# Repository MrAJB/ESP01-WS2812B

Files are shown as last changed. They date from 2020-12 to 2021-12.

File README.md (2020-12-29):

## Introduction
This repo documents the development of a small ESP-01 breakout board to support controlling two WS2812B LED strips and a Dallas DS18B20 temperature sensor. This allows for easy integration with HomeAssistant through ESPHome. 

Note that I'm just developing this stuff in my spare time and I'm far from an expert. Development may be slow and I cannot make any promises on the quality of this board. However, feel free to look around, maybe there's something useful for you in there!

## Hardware Overview
A schematic overview of the breakout board can be found [here](Hardware/esp01-ws2812b-breakout.pdf). As an be seen, this simple board allows to fit an ESP-01. Furthermore, it contains two level-shifters to control 5V data lines. The board is prepared to mount a DS18B20 temperature sensor, if desired. Lastly, a header to interface with the GPIO0 pin can be added, to further expand this board.

The layout and routing of V1 are finished:
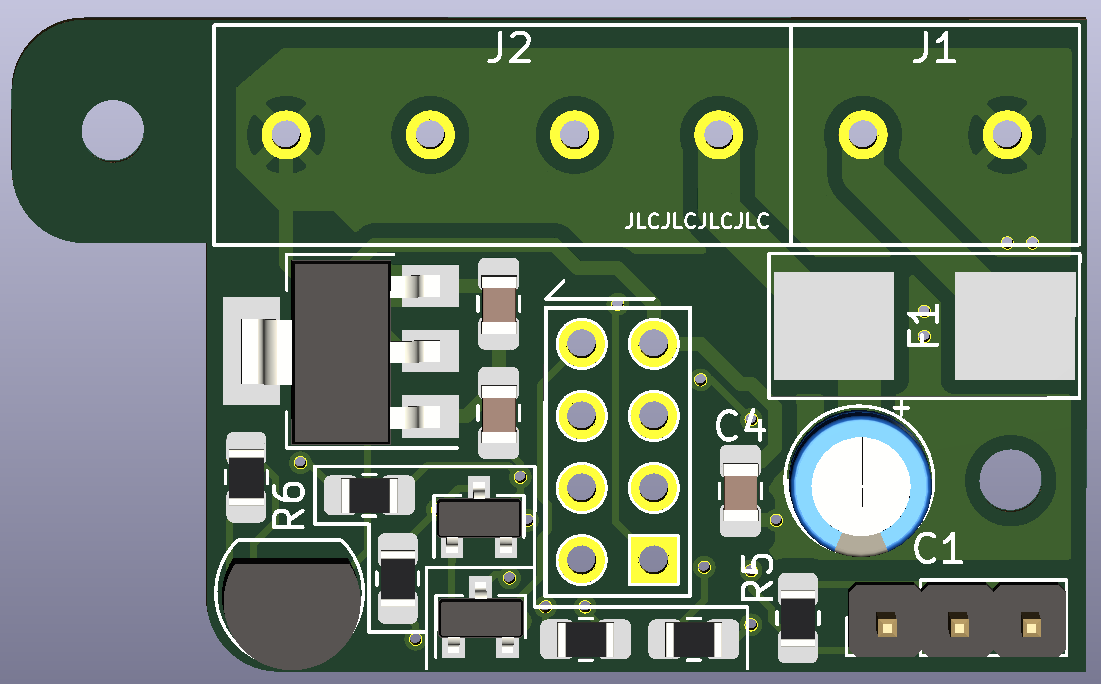
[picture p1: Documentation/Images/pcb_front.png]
pcb_front

(Note: the cutout in the lower left section aims to provide clearance for the WiFi antenna to improve the ESP's WiFi range.)

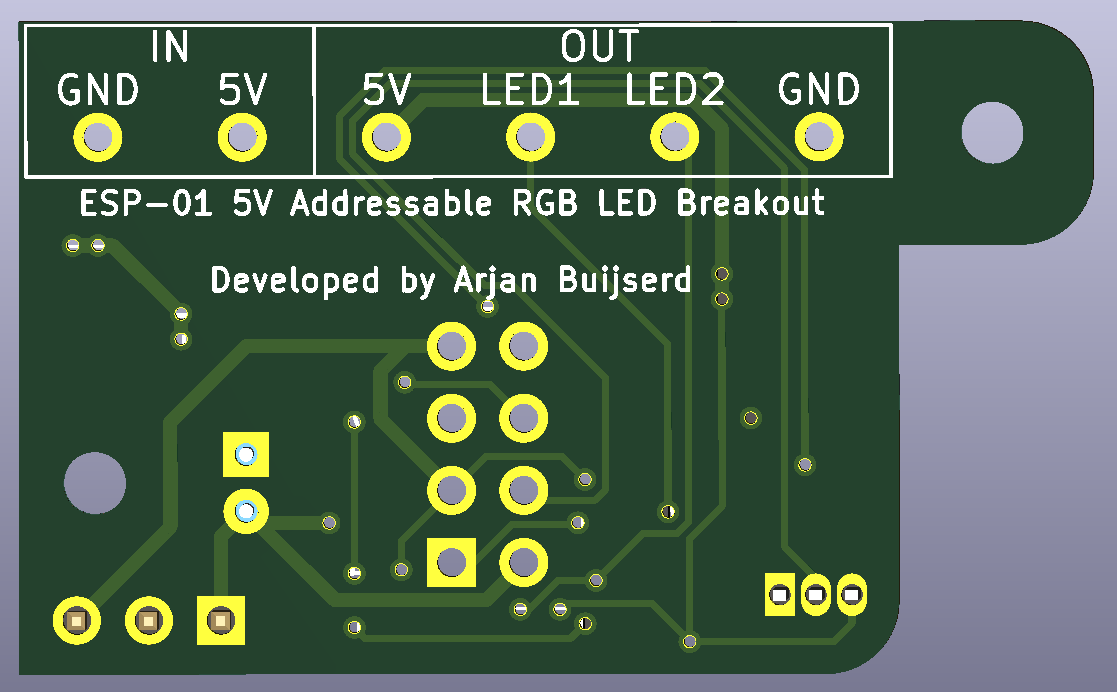
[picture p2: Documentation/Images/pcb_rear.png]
pcb_rear


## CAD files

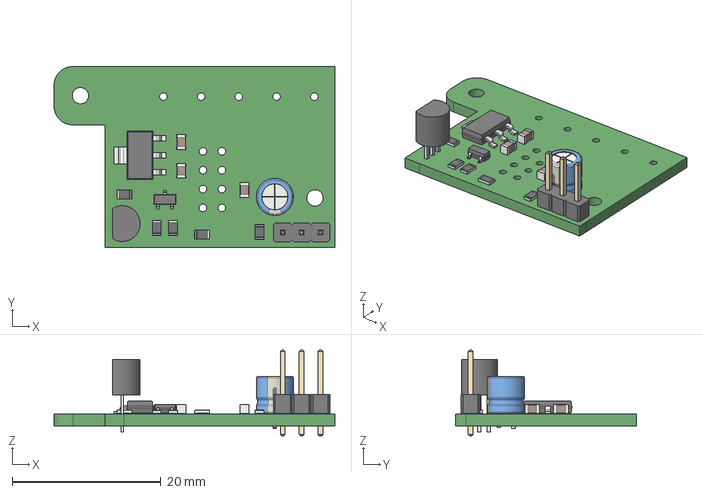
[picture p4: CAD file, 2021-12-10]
Hardware_Housing/esp01-ws2812b-breakout.step
37.8 x 24.4 x 11.5 mm

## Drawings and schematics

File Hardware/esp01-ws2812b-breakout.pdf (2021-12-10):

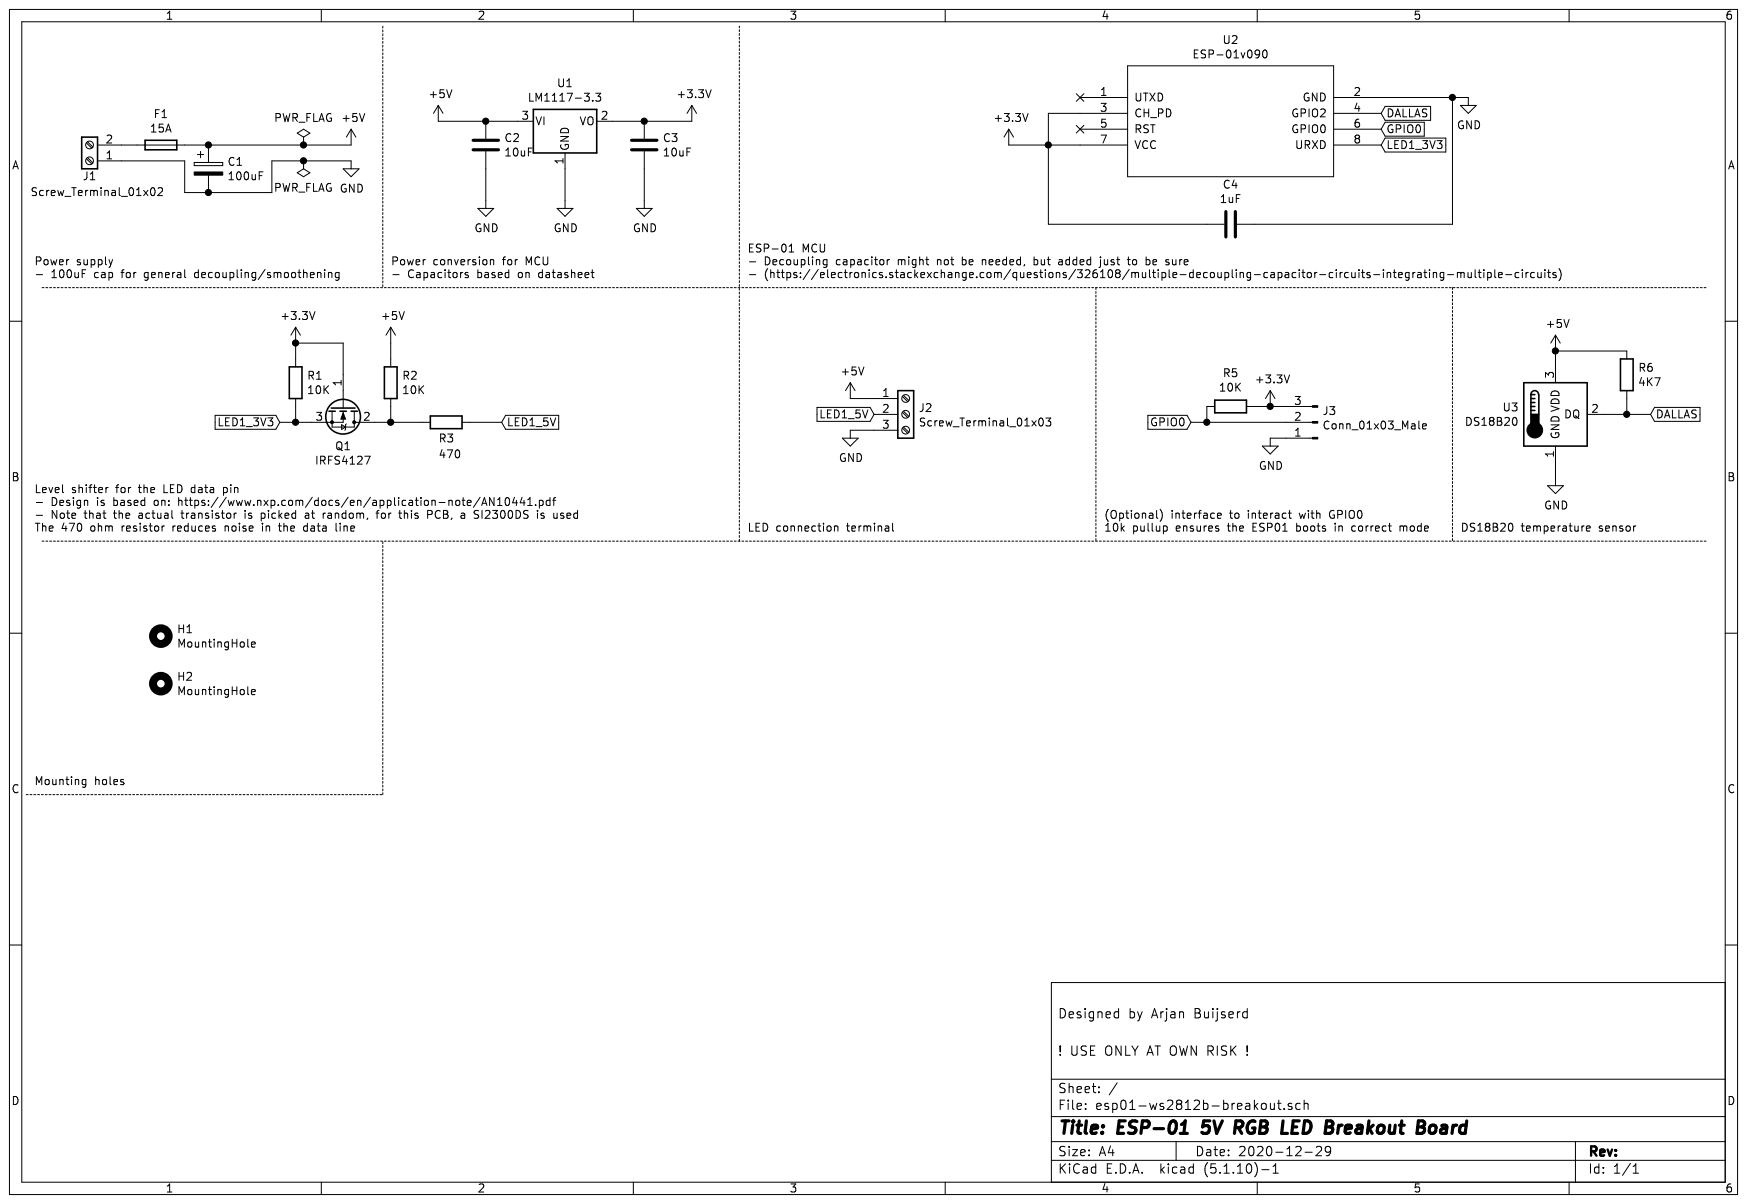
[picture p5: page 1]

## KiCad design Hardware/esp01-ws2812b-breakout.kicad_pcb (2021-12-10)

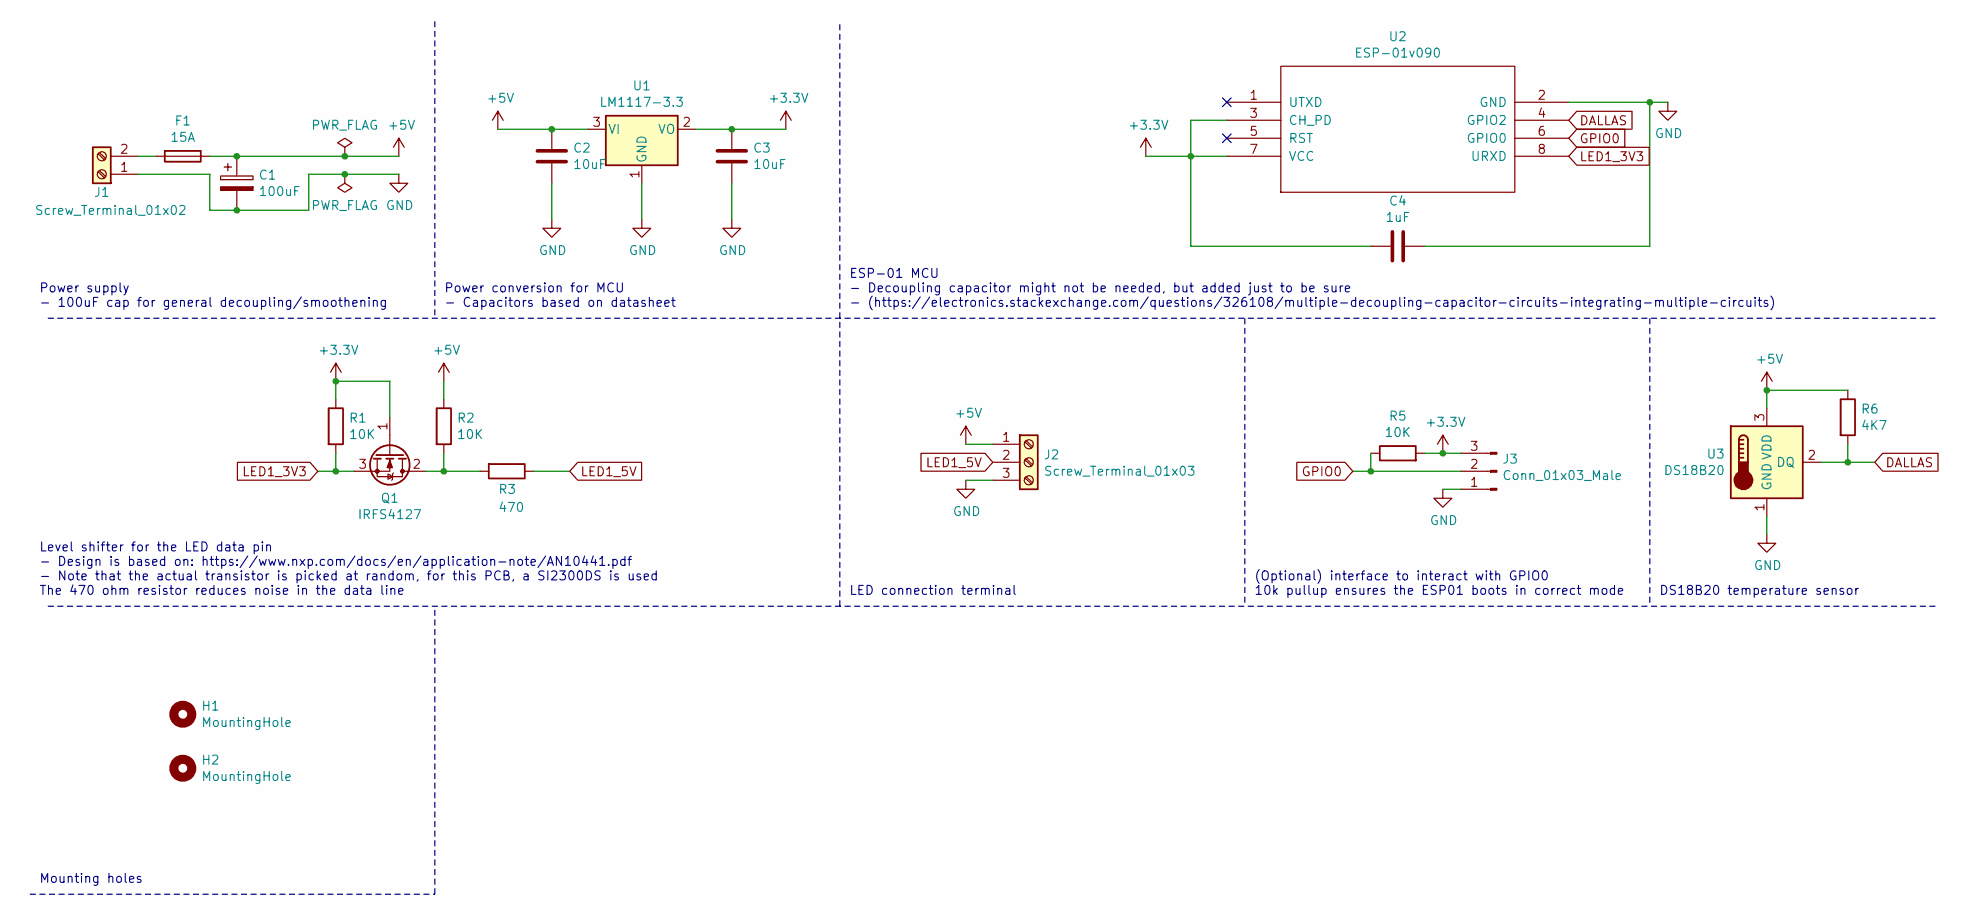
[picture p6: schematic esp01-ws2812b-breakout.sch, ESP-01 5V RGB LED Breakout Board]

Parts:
C1: 100uF; CP_Radial_D5.0mm_P2.00mm
C2, C3: 10uF; C_0805_2012Metric_Pad1.18x1.45mm_HandSolder
C4: 1uF; C_0805_2012Metric_Pad1.18x1.45mm_HandSolder
F1: 15A; 1808_SMD_Fuse_Holder
H1, H2: MountingHole; MountingHole_2.2mm_M2
J1: Screw_Terminal_01x02; 0102-blue-terminal
J2: Screw_Terminal_01x03; 0103-blue-terminal
J3: Conn_01x03_Male; PinHeader_1x03_P2.54mm_Vertical
Q1: IRFS4127; SOT-23_DS-REVERSED
R1, R2, R5: 10K; R_0805_2012Metric_Pad1.20x1.40mm_HandSolder
R3: 470; R_0805_2012Metric_Pad1.20x1.40mm_HandSolder
R6: 4K7; R_0805_2012Metric_Pad1.20x1.40mm_HandSolder
U1: LM1117-3.3; SOT-223
U2: ESP-01v090; ESP-01
U3: DS18B20; TO-92_Inline

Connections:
+3V3: C3.1, C4.2, J3.3, Q1.1 (G), R1.1, R5.2, U1.2 (VO), U2.3 (CH_PD), U2.7 (VCC)
+5V: C1.1, C2.1, F1.1, J2.1, R2.1, R6.1, U1.3 (VI), U3.3 (VDD)
DALLAS: R6.2, U2.4 (GPIO2), U3.2 (DQ)
GND: C1.2, C2.2, C3.2, C4.1, J1.1, J2.3, J3.1, U1.1 (GND), U2.2 (GND), U3.1 (GND)
GPIO0: J3.2, R5.1, U2.6 (GPIO0)
LED1_3V3: Q1.3 (S), R1.2, U2.8 (URXD)
LED1_5V: J2.2, R3.1
unnamed: F1.2, J1.2
unnamed: Q1.2 (D), R2.2, R3.2

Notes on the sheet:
ESP-01 MCU - Decoupling capacitor might not be needed, but added just to be sure - (https://electronics.stackexchange.com/questions/326108/multiple-decoupling-capacitor-circuits-integrating-multiple-circuits)
Level shifter for the LED data pin - Design is based on: https://www.nxp.com/docs/en/application-note/AN10441.pdf - Note that the actual transistor is picked at random, for this PCB, a SI2300DS is used The 470 ohm resistor reduces noise in the data line
LED connection terminal
DS18B20 temperature sensor
Mounting holes
(Optional) interface to interact with GPIO0 10k pullup ensures the ESP01 boots in correct mode
Power conversion for MCU - Capacitors based on datasheet
Power supply - 100uF cap for general decoupling/smoothening

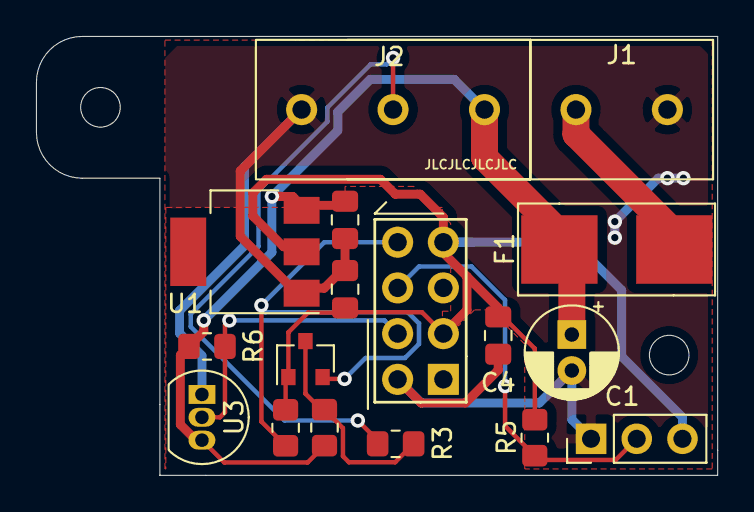
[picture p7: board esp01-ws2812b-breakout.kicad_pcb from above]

Board: 2 copper layers, 37.8 x 24.4 mm, 19 parts (0 on the bottom side), 9 nets.

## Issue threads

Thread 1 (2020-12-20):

WS2812B is 5V logic

MrAJB, 2020-12-20:
Create and test a simple logic level shifter to control the WS2812B with the ESP01:

https://hackaday.com/2016/12/05/taking-it-to-another-level-making-3-3v-and-5v-logic-communicate-with-level-shifters/

MrAJB, 2020-12-21:
Implemented logic level shifter and tested: LED is stable now.

Closed 2020-12-21.

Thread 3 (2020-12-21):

Supply voltage capacitor size TBD

MrAJB, 2020-12-21:
TODO:
- [x] Select the exact capacitor used
- [x] Assign the correct footprint
- [x] Update the PCB

MrAJB, 2020-12-21:
Done!

Closed 2020-12-21.

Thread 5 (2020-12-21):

Check C and R footprints

MrAJB, 2020-12-21:
Double check the footprints of all capacitors and resistors to make sure they match what parts I've actually ordered.

MrAJB, 2020-12-22:
Capacitors are 0603, resistors are 0805. Needs to be updated...

MrAJB, 2020-12-23:
Done, all is 0805 now.

Closed 2020-12-23.

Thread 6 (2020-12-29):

Check MOSFET's S-D orientation

MrAJB, 2020-12-29:
Double check if the source and drain of the MOSFET's are correctly placed on the PCB.

MrAJB, 2020-12-29:
Checked: they are correct.

Closed 2020-12-29.

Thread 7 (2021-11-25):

Check correct pin for LED

MrAJB, 2021-11-25:
It appeared that one pin was not suitable for driving the LED, as the ESP would not boot anymore. Check if the correct pin is now being used w.r.t. the pin in the test setup.

MrAJB, 2021-12-02:
It's the LED2 output terminal that works properly.

MrAJB, 2021-12-02:
Done!

Closed 2021-12-02.

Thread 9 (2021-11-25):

Terminal clashes with fuse holder

MrAJB, 2021-11-25:
There's too little space for the fuse holder, it interferes with the input terminal, add some space to allow for proper fit.

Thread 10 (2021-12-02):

Add 470ohm resistor to LED out

MrAJB, 2021-12-02:
Reduce signal noise of LED output

MrAJB, 2021-12-02:
Done!

Closed 2021-12-02.

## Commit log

2020-12-20 PCB schematic created
    [esp01-ws2812b-breakout.kicad_pcb, esp01-ws2812b-breakout.sch]
2020-12-21 Included level shifters for LED data pins
    [esp01-ws2812b-breakout.sch]
2020-12-21 Schematics completed, PCB design started
    [esp01-ws2812b-breakout.kicad_pcb, esp01-ws2812b-breakout.sch]
2020-12-21 Moved KiCad files to root hardware folder
    [esp01-ws2812b-breakout.kicad_pcb, esp01-ws2812b-breakout.sch]
2020-12-21 Updated capacitor footprint and NETlist
    [esp01-ws2812b-breakout.sch]
2020-12-21 Updated custom footprint libraries
2020-12-21 Finished PCB layout
    [esp01-ws2812b-breakout.kicad_pcb, esp01-ws2812b-breakout.sch]
2020-12-23 Changed decoupling capacitors layout
    [esp01-ws2812b-breakout.sch]
2020-12-23 Defined footprints and added SMD fuse print
    [esp01-ws2812b-breakout.sch]
2020-12-23 Finished schematics and footprint revisions
    [esp01-ws2812b-breakout.sch]
2020-12-23 Resistor footprints were still 0603, fixed now.
    [esp01-ws2812b-breakout.kicad_pcb, esp01-ws2812b-breakout.sch]
2020-12-23 Antenna clearance, redid layout
    Some sources comment that the ESP8266's WiFi range can be extended dramatically by having the antenna 'sticking' out from the PCB. So I decided to inplement that. Additionally, the new footprints required me to redo the entire layout.
    [esp01-ws2812b-breakout.kicad_pcb]
2020-12-23 Updated PDF schematic
2020-12-23 Layout updates
    [esp01-ws2812b-breakout.kicad_pcb]
2020-12-23 Fixed schematic of pull-up resistor
    [esp01-ws2812b-breakout.sch]
2020-12-23 Started routing
    [esp01-ws2812b-breakout.kicad_pcb]
2020-12-23 Continued routing
    [esp01-ws2812b-breakout.kicad_pcb]
2020-12-29 Finished PCB routing
    [esp01-ws2812b-breakout.kicad_pcb]
2020-12-29 Finalized PCB layout, added PDF+PNG
    [esp01-ws2812b-breakout.kicad_pcb, esp01-ws2812b-breakout.sch]
2021-10-08 Checked an finalized designs for production
    [esp01-ws2812b-breakout.sch]
2021-10-08 Generated production files
    [esp01-ws2812b-breakout-B_Cu.gbl, esp01-ws2812b-breakout-B_Mask.gbs, esp01-ws2812b-breakout-B_SilkS.gbo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]
2021-10-08 No real changes, just save the files
    [esp01-ws2812b-breakout.kicad_pcb]
2021-11-25 Removed second LED channel
    [esp01-ws2812b-breakout.sch]
2021-12-02 Updated to correct LED pin
    [esp01-ws2812b-breakout.sch]
2021-12-02 Started re-doing the PCB layout
    [esp01-ws2812b-breakout.kicad_pcb, esp01-ws2812b-breakout.sch]
2021-12-03 Updated PCB layout, removed obsolete traces
    [esp01-ws2812b-breakout.kicad_pcb]
2021-12-10 Updated schematic export, finished PCB design
    [esp01-ws2812b-breakout.kicad_pcb, esp01-ws2812b-breakout.sch]
2021-12-10 Cosmetic tweaks
    [esp01-ws2812b-breakout.kicad_pcb]
2021-12-10 Generated STEP export of PCB
    [esp01-ws2812b-breakout.step]
